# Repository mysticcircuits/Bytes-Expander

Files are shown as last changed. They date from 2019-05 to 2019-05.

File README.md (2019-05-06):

# Bytes-Expander
Variable Loop Length Turing Machine Expander

A 3rd party Turing Machine expander which allows for voltage control over the loop length of the host device.  It will require 
some modifications to the host Turing Machine which have only been tested with the Turing v1, but it is hypothetically
possible to modify the v2 to do accept the expander too.  There are instructions for the v1 modifications in the instructions
folder.

For questions or help building the module check out the relevant thread on MW.

http://www.muffwiggler.com/forum/viewtopic.php?p=1646194#1646194

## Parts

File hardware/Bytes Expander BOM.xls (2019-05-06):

BYTES EXPANDER BOM |  |  | NON MOUSER PARTS:
Mouser # | Part # | Manufacturer | Web Link | Quantity | Notes
 | RD901F-20-15R1-100KB | Alpha | http://smallbear-electronics.mybigcommerce.com/alpha-single-gang-9mm-pc-mount/ | 3 | Order the 100k Linear version
 | 1MS3T1B1C0M1QE | Taiway | http://smallbear-electronics.mybigcommerce.com/spdt-center-off/ | 1 | Cheaper version of NKK switch below
 | PJ302M | Kobiconn | https://www.thonk.co.uk/shop/3-5mm-jacks/ | 1
 |  |  | https://modularaddict.com/parts/jacks/pj302m-jacks |  | only available as bag of 50
 |  |  | https://www.digikey.com/products/en?x=0&y=0&lang=en&site=us&keywords=cp-3536-nd
 |  |  | Description – Mouser Parts
576-250R120 | 250R120U | Littelfuse | Resettable Fuses - PPTC 0.12A 250V RADIAL | 1
625-1N5817-E3/73 | 1N5817-E3/73 | Vishay | Schottky Diodes & Rectifiers Vr/20V Io/1A | 6
660-MF1/4D52R1003F | MF1/4DCT52R1003F | KOA Speer | Metal Film Resistors - Through Hole 100Kohms 1% 100PPM | 2
660-MF1/4DCT52R2201F | MF1/4DCT52R2201F | KOA Speer | Metal Film Resistors - Through Hole 1/4W 2.2K ohm 1% 2.2K OHM 1% | 5
660-MF1/4DC4703F | MF1/4DC4703F | KOA Speer | Metal Film Resistors - Through Hole 470K 1% 100PPM | 10
594-K103K15X7RF5TL2 | K103K15X7RF5TL2 | Vishay | Multilayer Ceramic Capacitors MLCC - Leaded 0.01uF 50volts 10% X7R 2.5mm LS | 6
595-CD4051BE | CD4051BE | Texas Instruments | Multiplexer Switch ICs 8-Channel Analog | 2
649-DILB20P-223TLF | DILB20P-223TLF | FCI / Amphenol | IC & Component Sockets .3CL 20 PIN TIN/TIN | 2
863-MC78L09ABPRAG | MC78L09ABPRAG | ON Semiconductor | Linear Voltage Regulators 9V 100mA Positive | 1
700-ADC0820CCN | ADC0820CCN+ | Maxim Integrated | Analog to Digital Converters - ADC CMOS High-Speed 8 Bit w/Track & Hold | 2
652-3296Y-1-104LF | 3296Y-1-104LF | Bourns | Trimmer Resistors - Through Hole 3/8" 100Kohms Sealed Vertical Adjust | 1
649-DILB8P223TLF | DILB8P-223TLF | FCI / Amphenol | IC & Component Sockets 8P IC SOCKET | 1
571-1-2199298-3 | 1-2199298-3 | TE Connectivity | IC & Component Sockets 14P DIP SKT 300 CL LADDER | 1
571-1-2199298-4 | 1-2199298-4 | TE Connectivity | IC & Component Sockets 16P DIP SKT 300 CL LADDER | 3
595-TL074ACNE4 | TL074ACNE4 | Texas Instruments | Operational Amplifiers - Op Amps Low-Noise JFET-Input Op Amp | 1
595-TL072IP | TL072IP | Texas Instruments | Operational Amplifiers - Op Amps Dual JFET In Low N | 1
571-9-146284-0 | 9-146284-0 | TE Connectivity | Headers & Wire Housings 40 MODII HDR SRST B/A .100CL | 1
517-929974-01-13-RK | 929974-01-13-RK | 3M | Headers & Wire Housings 13 CON STR BRDMNT SKT | 1
633-M2013S2A1W01 | M2013S2A1W01 | NKK Switches | Toggle Switches ON-OFF-ON .200 BAT 1/4" BSHING SLDR LUG | 1

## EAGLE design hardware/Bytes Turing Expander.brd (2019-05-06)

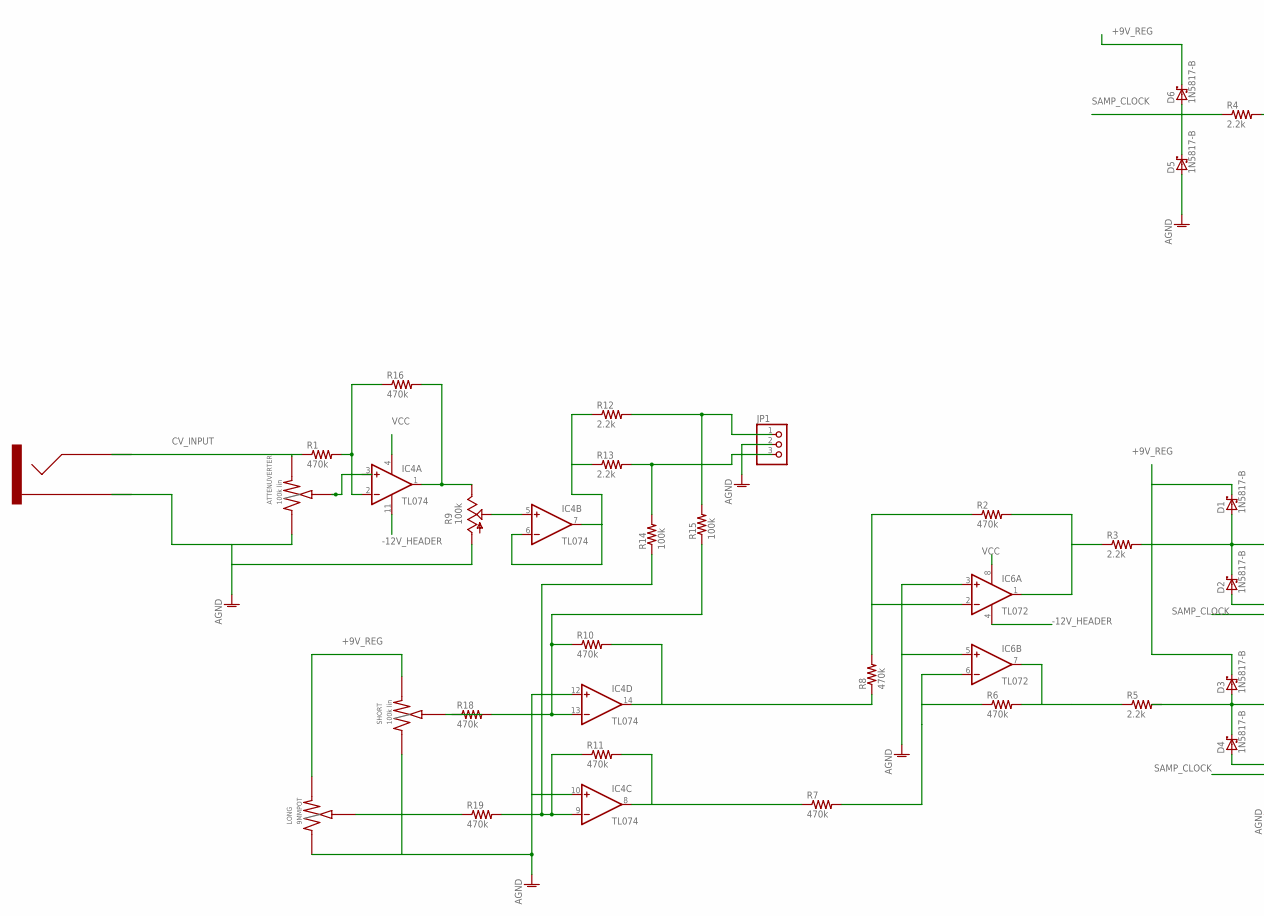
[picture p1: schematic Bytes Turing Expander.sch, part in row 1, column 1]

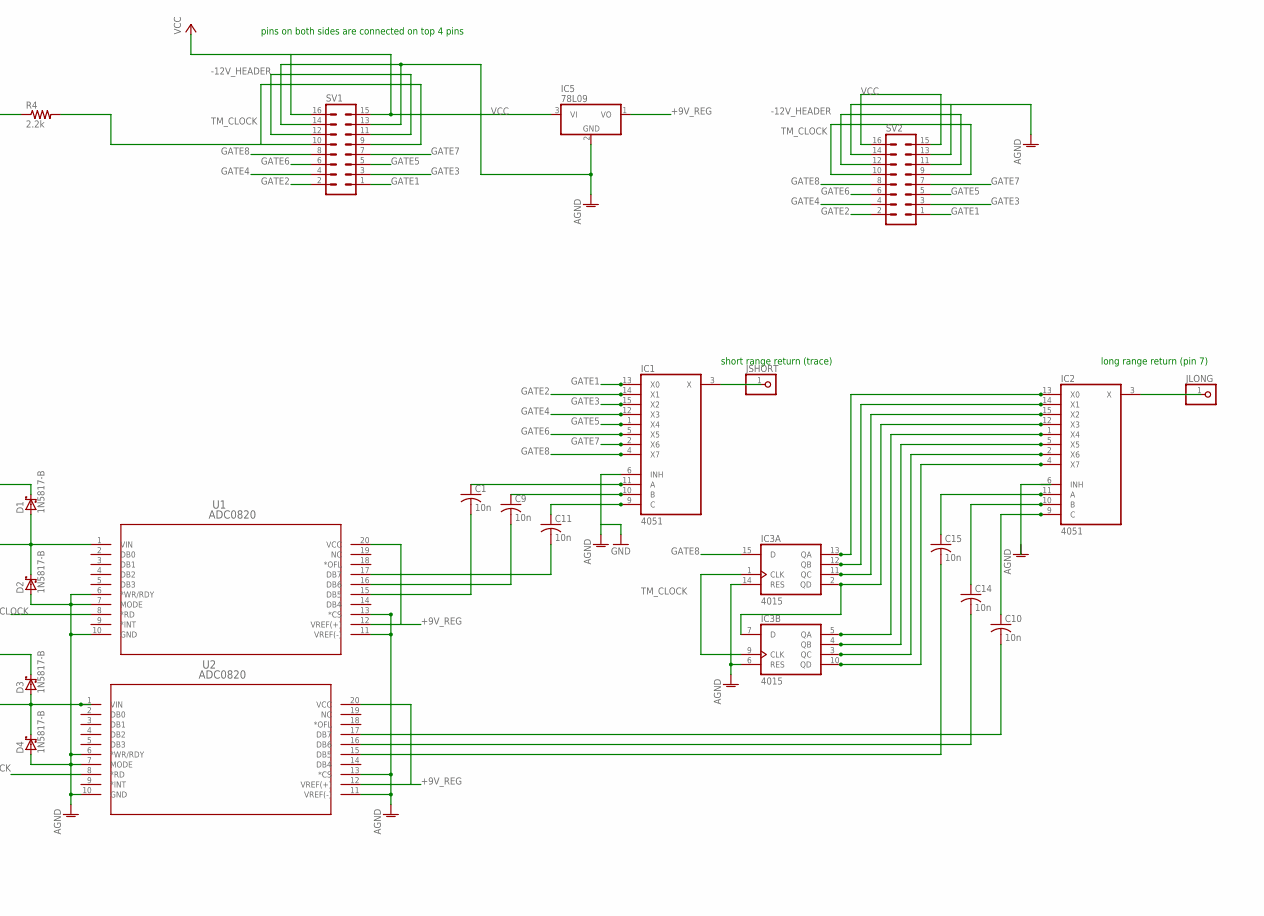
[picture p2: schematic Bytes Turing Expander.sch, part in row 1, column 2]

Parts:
ATTENUVERTER: 100k lin; 9MMPOT
C1, C9, C10, C11, C14, C15: 10n; C025-024X044
D1, D2, D3, D4, D5, D6: 1N5817-B; DO41-7.6
IC1, IC2: 4051; DIL16
IC3: 4015; DIL16
IC4: TL074; DIL14
IC5: 78L09; TO92
IC6: TL072; DIL08
JLONG: PINHD-1X1; 1X01
JP1: PINHD-1X3; 1X03
JSHORT: PINHD-1X1; 1X01
LONG: 9MMPOT
R1, R2, R6, R7, R8, R10, R11, R16, R18, R19: 470k; 0204V
R3, R4, R5, R12, R13: 2.2k; 0204V
R9: 100k; B64Y
R14, R15: 100k; 0204V
SHORT: 100k lin; 9MMPOT
SV1, SV2: MA08-2
U1, U2: ADC0820; NFH20
U$1: 3.5MMJACK; 3.5MMPHONEJACK

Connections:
+9V_REG: D1.C, D3.C, D6.C, IC5.1 (VO), LONG.LEFT (RIGHT), SHORT.LEFT (RIGHT), U1.12 (VREF(+)), U1.20 (VCC), U2.12 (VREF(+)), U2.20 (VCC)
-12V_HEADER: IC4.11 (V-), IC6.4 (V-), SV1.11, SV1.12, SV2.11, SV2.12
AGND: ATTENUVERTER.RIGHT (LEFT), D2.A, D4.A, D5.A, IC1.6 (INH), IC1.7 (VEE), IC1.8 (GND), IC2.7 (VEE), IC2.8 (GND), IC3.6 (RES), IC3.14 (RES), IC4.10 (+IN), IC4.12 (+IN), IC5.2 (GND), IC6.3 (+IN), IC6.5 (+IN), JP1.2, LONG.RIGHT (LEFT), R9.A, SHORT.RIGHT (LEFT), SV1.13, SV1.14, SV2.13, SV2.14, U1.6 (*WR/RDY), U1.7 (MODE), U1.10 (GND), U1.11 (VREF(-)), U1.13 (*CS), U2.6 (*WR/RDY), U2.7 (MODE), U2.10 (GND), U2.11 (VREF(-)), U2.13 (*CS), U$1.SLEEVE
CV_INPUT: ATTENUVERTER.LEFT (RIGHT), R1.1, U$1.TIP
GATE1: IC1.13 (X0), SV1.1, SV2.1
GATE2: IC1.14 (X1), SV1.2, SV2.2
GATE3: IC1.15 (X2), SV1.3, SV2.3
GATE4: IC1.12 (X3), SV1.4, SV2.4
GATE5: IC1.1 (X4), SV1.5, SV2.5
GATE6: IC1.5 (X5), SV1.6, SV2.6
GATE7: IC1.2 (X6), SV1.7, SV2.7
GATE8: IC1.4 (X7), IC3.15 (D), SV1.8, SV2.8
JSHORT: IC1.3 (X), JSHORT.1
unnamed: IC4.2 (-IN), R1.2, R16.1
unnamed: IC4.1 (OUT), R9.E, R16.2
unnamed: LONG.CENTER, R19.1
unnamed: R18.1, SHORT.CENTER
unnamed: IC4.6 (-IN), IC4.7 (OUT), R12.1, R13.1
unnamed: IC4.5 (+IN), R9.S
unnamed: IC6.1 (OUT), R2.2, R3.1
unnamed: IC4.9 (-IN), R11.1, R14.1, R19.2
unnamed: IC2.12 (X3), IC3.2 (QD), IC3.7 (D)
unnamed: C11.1, IC1.9 (C)
unnamed: IC2.13 (X0), IC3.13 (QA)
unnamed: IC2.14 (X1), IC3.12 (QB)
unnamed: IC2.15 (X2), IC3.11 (QC)
unnamed: IC2.1 (X4), IC3.5 (QA)
unnamed: IC2.5 (X5), IC3.4 (QB)
unnamed: IC2.2 (X6), IC3.3 (QC)
unnamed: IC2.4 (X7), IC3.10 (QD)
unnamed: IC4.14 (OUT), R8.1, R10.2
unnamed: IC6.7 (OUT), R5.1, R6.2
unnamed: IC4.8 (OUT), R7.1, R11.2
unnamed: JP1.3, R13.2, R14.2
unnamed: C9.1, IC1.10 (B)
unnamed: C1.1, IC1.11 (A)
unnamed: C11.2, U1.17 (DB7)
unnamed: C9.2, U1.16 (DB6)
unnamed: C1.2, U1.15 (DB5)
unnamed: C10.1, IC2.9 (C)
unnamed: C15.1, IC2.11 (A)
unnamed: C14.1, IC2.10 (B)
unnamed: IC6.2 (-IN), R2.1, R8.2
unnamed: C15.2, U2.15 (DB5)
unnamed: C14.2, U2.16 (DB6)
unnamed: C10.2, U2.17 (DB7)
unnamed: JP1.1, R12.2, R15.2
unnamed: ATTENUVERTER.CENTER, IC4.3 (+IN)
unnamed: IC4.13 (-IN), R10.1, R15.1, R18.2
unnamed: IC6.6 (-IN), R6.1, R7.2
unnamed: IC2.3 (X), JLONG.1
unnamed: D3.A, D4.C, R5.2, U2.1 (VIN)
unnamed: D1.A, D2.C, R3.2, U1.1 (VIN)
SAMP_CLOCK: D5.C, D6.A, R4.1, U1.8 (*RD), U2.8 (*RD)
TM_CLOCK: IC3.1 (CLK), IC3.9 (CLK), R4.2, SV1.9, SV1.10, SV2.9, SV2.10
VCC: IC1.16 (VCC), IC2.16 (VCC), IC3.16 (VDD), IC4.4 (V+), IC5.3 (VI), IC6.8 (V+), SV1.15, SV1.16, SV2.15, SV2.16
VSS: IC3.8 (VSS)

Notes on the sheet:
short range return (trace)
long range return (pin 7)
pins on both sides are connected on top 4 pins

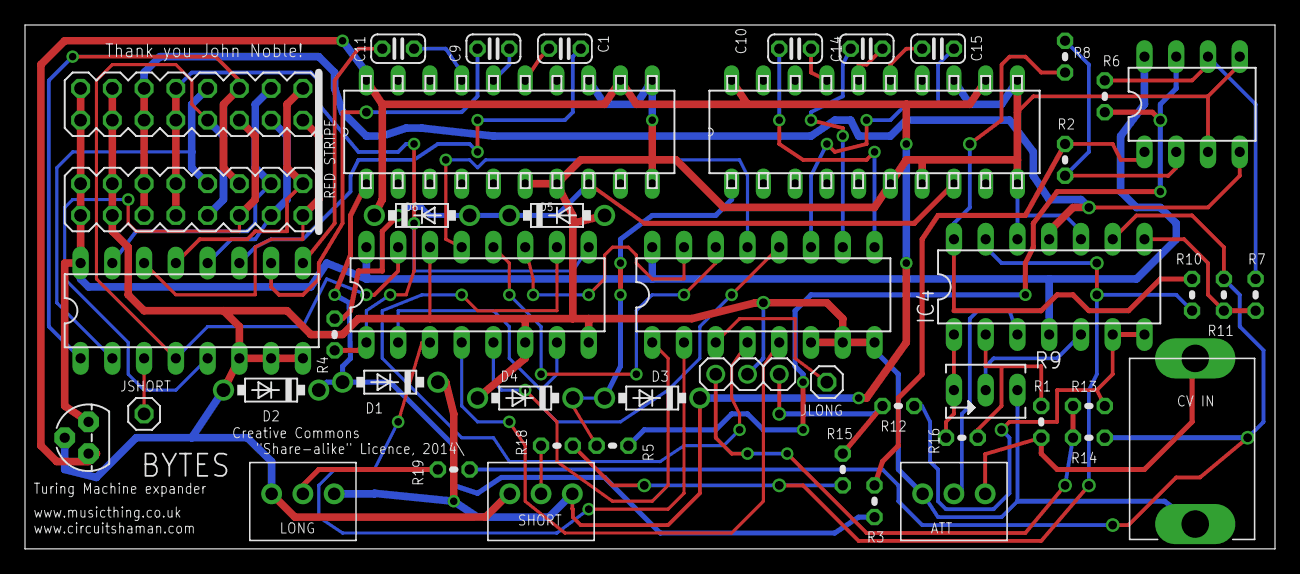
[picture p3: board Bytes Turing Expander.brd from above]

Board: 2 copper layers, 100.0 x 41.9 mm, 47 parts (0 on the bottom side), 56 nets.

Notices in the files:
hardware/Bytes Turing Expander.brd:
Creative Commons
